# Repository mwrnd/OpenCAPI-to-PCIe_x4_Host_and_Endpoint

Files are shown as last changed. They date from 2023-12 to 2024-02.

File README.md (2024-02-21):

**Work-In-Progress**: Design being tested.

# OpenCAPI to PCIe x4 Host and Endpoint

Designed to test simultaneous PCIe Host and Endpoint operation with the Innova-2.

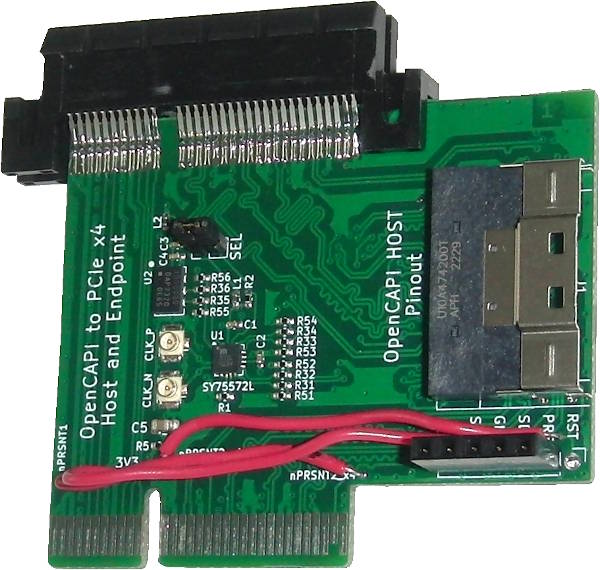
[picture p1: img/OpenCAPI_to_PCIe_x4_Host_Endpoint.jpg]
OpenCAPI to PCIe x4 Host and Endpoint Adapter


There are two [PCIE4](https://docs.xilinx.com/r/en-US/pg213-pcie4-ultrascale-plus/Introduction) blocks in the column of the Innova-2's OpenCAPI Quads.

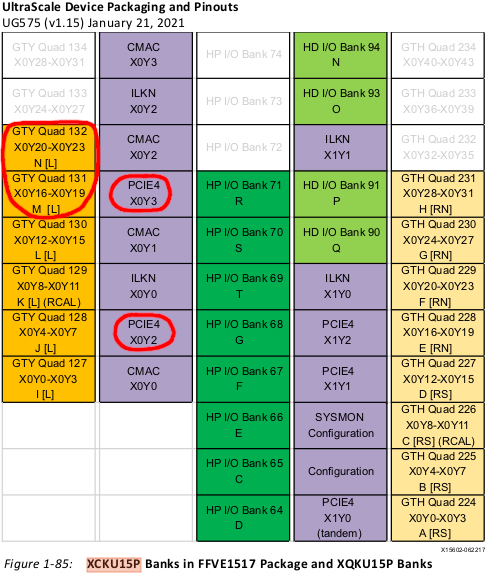
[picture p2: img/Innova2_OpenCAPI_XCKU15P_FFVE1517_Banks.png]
Innova-2 OpenCAPI Banks


The GTY Transceivers connected to the OpenCAPI Connector are in a column that does not contain the Configuration Block so it is impossible for the FPGA to be programmed within the [100ms PCIe power-up time limit](https://pcisig.com/specifications/ecr_ecn_process?speclib=100+ms). Motherboard boot must be delayed to allow the FPGA to configure itself before PCIe devices are enumerated. This can be accomplished by toggling the POWER button, then pressing and holding the RESET button for a second before releasing it. Or, [connect a capacitor across the reset pins of an ATX motherboard's Front Panel Header](https://github.com/mwrnd/ATX_Boot_Delay).

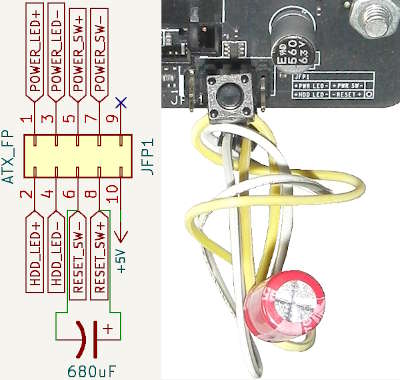
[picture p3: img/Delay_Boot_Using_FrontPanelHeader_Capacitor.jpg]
Delay Boot Using Front Panel Header Capacitor


[OpenCAPI](https://files.openpower.foundation/s/xSQPe6ypoakKQdq/download/25Gbps-spec-20171108.pdf)-compatible SlimSAS 8x uses a **Host** version of the OpenCAPI **Carrier** pinout from the [ADM-PCIE-9V5 User Manual (Pg15-19of38)](https://www.alpha-data.com/xml/user_manuals/adm-pcie-9v5%20user%20manual_v1_4.pdf).

## Testing

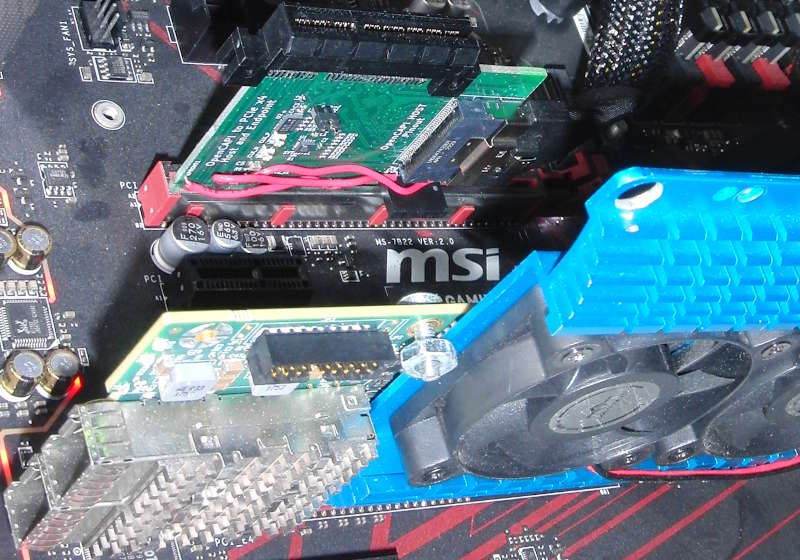
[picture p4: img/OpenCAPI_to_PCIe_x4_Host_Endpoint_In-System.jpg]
OpenCAPI to PCIe x4 Host and Endpoint in a System


```
TODO
```

### OpenCAPI I2C

The [innova2_xdma_opencapi](https://github.com/mwrnd/innova2_xdma_opencapi) project includes the ability to test I2C.

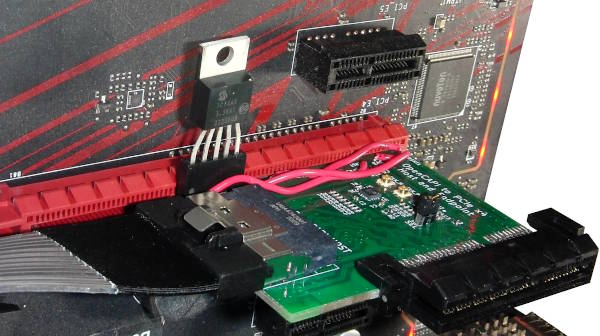
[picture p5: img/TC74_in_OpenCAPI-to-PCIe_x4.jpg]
Testing I2C using TC74


## PCB Layout

All differential pairs are length-matched to within 1mm intra-pair (N-to-P) and each group of differential pairs (e.g., TX0-to-TX3) is similarly matched to within 1mm.

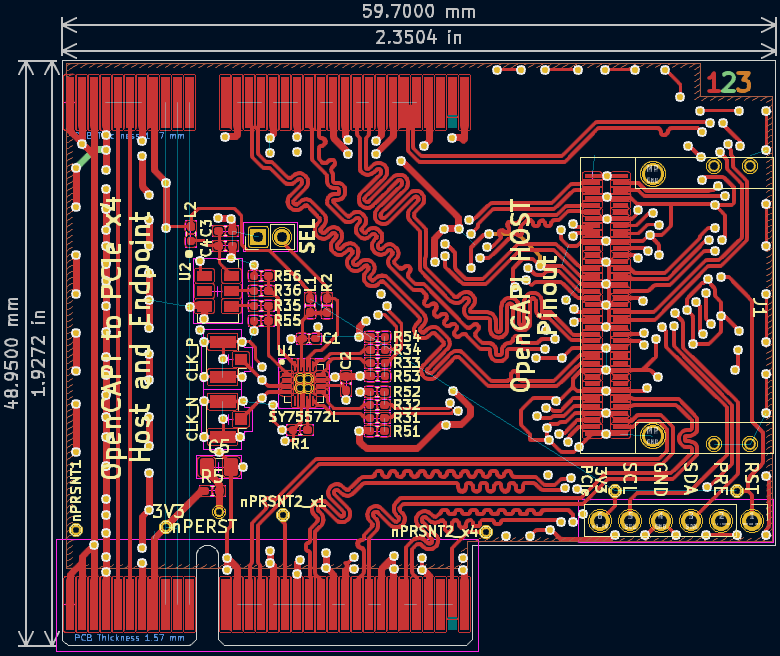
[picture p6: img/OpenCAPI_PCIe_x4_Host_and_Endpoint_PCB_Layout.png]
OpenCAPI to PCIe Host and Endpoint PCB Layout


## Schematic

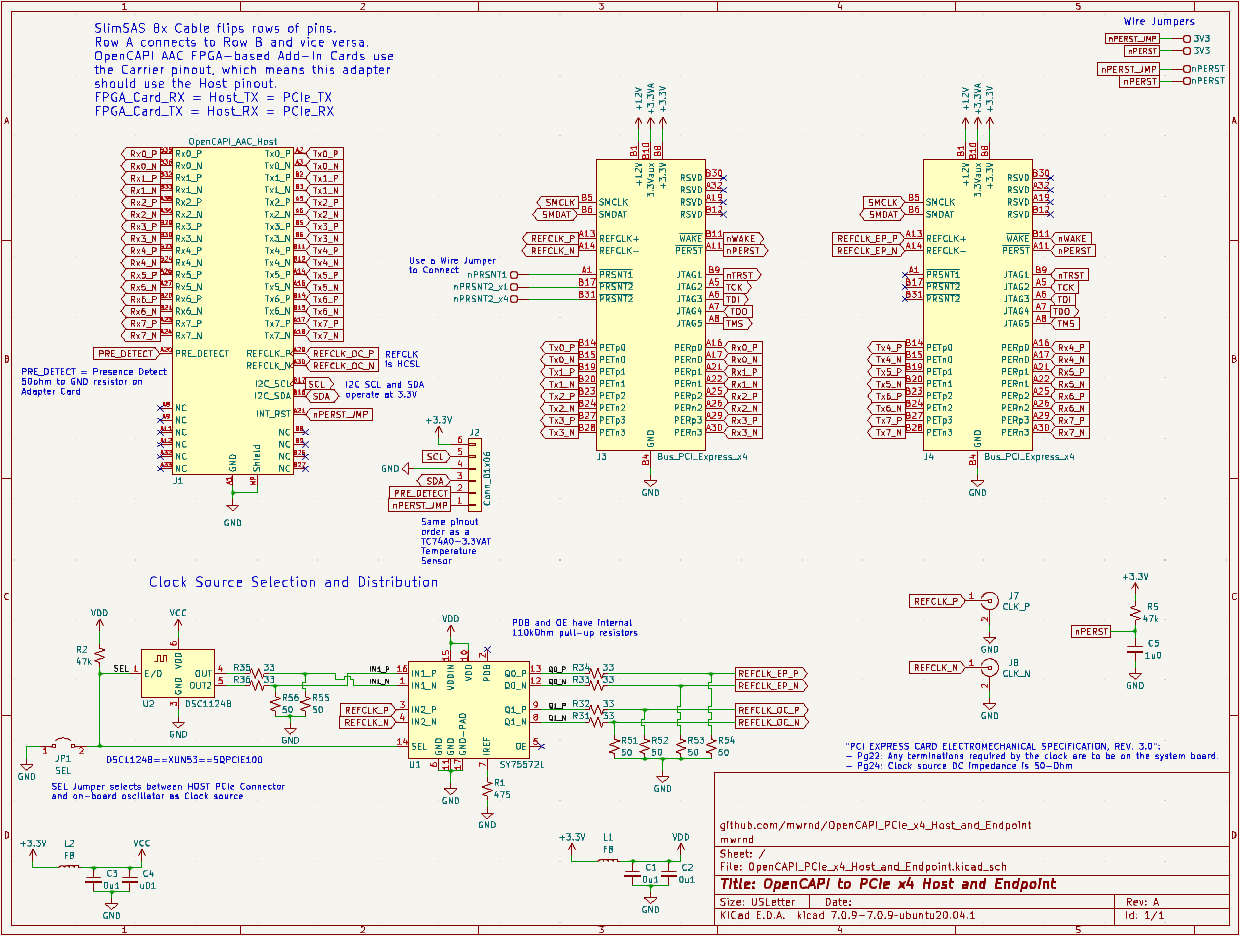
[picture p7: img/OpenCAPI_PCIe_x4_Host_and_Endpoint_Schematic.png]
OpenCAPI to PCIe Host and Endpoint Schematic


## Bill Of Materials

| Designator(s) | Part Number | Quantity | Value | Footprint | Availability |
| --- | --- | --- | --- | --- | --- |
| U1 | SY75572LMG | 1 | N/A | QFN-16-1EP_3x3mm_P0.5mm | [DigiKey](https://www.digikey.com/en/products/detail/microchip-technology/SY75572LMG-TR/5319585) |
| U2 | DSC1124BI2-100-0000 | 1 | N/A | OSC_SMD_IDT_JS6-6_5.0x3.2mm_P1.27mm | [DigiKey](https://www.digikey.com/en/products/detail/microchip-technology/DSC1124BI2-100-0000/5284202) |
| J1 | U10A474240T | 1 | N/A | SlimSAS_8x_RA_U10-A474 | [DigiKey](https://www.digikey.com/en/products/detail/amphenol-cs-commercial-products/U10A474240T/17066204) |
| J2 | PPPC061LFBN-RC | 1 | N/A | PinHeader_1x06_P2.54mm_Vertical | [DigiKey](https://www.digikey.com/en/products/detail/sullins-connector-solutions/PPPC061LFBN-RC/810178) |
| J4 | 2-2387405-2 | 1 | N/A | PCIe x4 Straddle Mount w/ Open End  | [DigiKey](https://www.digikey.com/en/products/detail/te-connectivity-amp-connectors/2-2387405-2/15221995) |
| JP1 | 2PH1-02-UA | 1 | N/A | PinHeader_1x02_P2.00mm_Vertical | [DigiKey](https://www.digikey.com/en/products/detail/adam-tech/2PH1-02-UA/9830305) |
| R31 to R36 | RT0402FRE0733RL | 6 | 33-Ohm | Resistor_SMD_R_0402_1005Metric | [DigiKey](https://www.digikey.com/en/products/detail/yageo/RT0402FRE0733RL/1071963) |
| R51 to R56 | RT0402FRE0749R9L | 6 | 49.9-Ohm | Resistor_SMD_R_0402_1005Metric | [DigiKey](https://www.digikey.com/en/products/detail/yageo/RT0402FRE0749R9L/1072042) |
| R1 | RT0402FRE07475RL | 1 | 475-Ohm | Resistor_SMD_R_0402_1005Metric | [DigiKey](https://www.digikey.com/en/products/detail/yageo/RT0402FRE07475RL/1072032) |
| R2, R5 | RT0402FRE0751KL | 2 | 51k-Ohm | Resistor_SMD_R_0402_1005Metric | [DigiKey](https://www.digikey.com/en/products/detail/yageo/RT0402FRE0751KL/1072058) |
| L1, L2 | BLM15PX601SN1D | 2 | 600@100MHz | Resistor_SMD_R_0402_1005Metric | [DigiKey](https://www.digikey.com/en/products/detail/murata-electronics/BLM15PX601SN1D/4421102) |
| C4 | KGM05AR71C103KH | 1 | 0.01uF | Capacitor_SMD_C_0402_1005Metric | [DigiKey](https://www.digikey.com/en/products/detail/kyocera-avx/KGM05AR71C103KH/563224) |
| C1, C2, C3 | KGM05AR51A104KH | 3 | 0.1uF | Capacitor_SMD_C_0402_1005Metric | [DigiKey](https://www.digikey.com/en/products/detail/kyocera-avx/KGM05AR51A104KH/563239) |
| C5 | CL21B105KAFNNNE | 1 | 1uF | Capacitor_SMD_C_0805_2012Metric | [DigiKey](https://www.digikey.com/en/products/detail/samsung-electro-mechanics/CL21B105KAFNNNE/3886724) |
| J7, J8 | 2337019-1 | 2 | U.FL(UMCC) | U.FL_Hirose | [DigiKey](https://www.digikey.com/en/products/detail/te-connectivity-amp-connectors/2337019-1/9974052) |
| Jumper | SPN02SYBN-RC | 1 | N/A | 2mm Shunt | [DigiKey](https://www.digikey.com/en/products/detail/sullins-connector-solutions/SPN02SYBN-RC/927356) |

**Optional**: [TC74Ax-3-3VAT](https://www.digikey.com/en/products/detail/microchip-technology/TC74A0-3-3VAT/442720) I2C Temperature Sensor for testing I2C.

## Assembly Notes

Use needle-nosed pliers to remove the PCIe x4 Connector's mounting post.

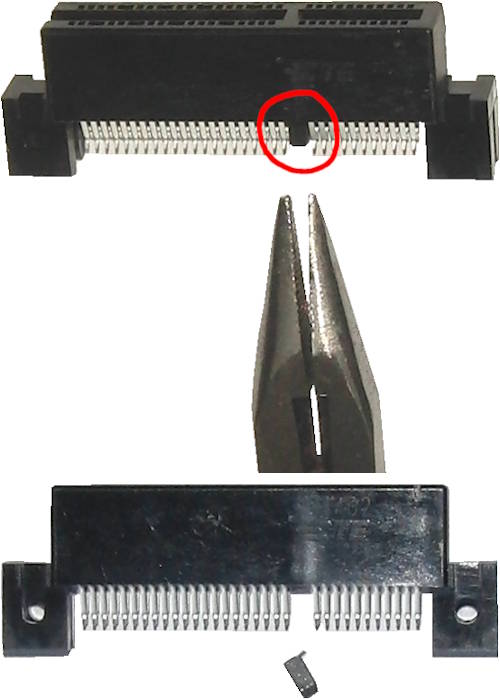
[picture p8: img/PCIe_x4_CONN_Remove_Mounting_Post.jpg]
Remove PCIe x4 CONNECTOR Mounting Post


Three wire jumpers are needed to connect `3V3==3V3_PCIe`, `nPERST==RST`, and `nPRSNT1==nPRSNT2_x4`.

## PCB Layer Stackup

4-Layer PCB stackup taken from [JLCPCB](https://jlcpcb.com/capabilities/pcb-capabilities).

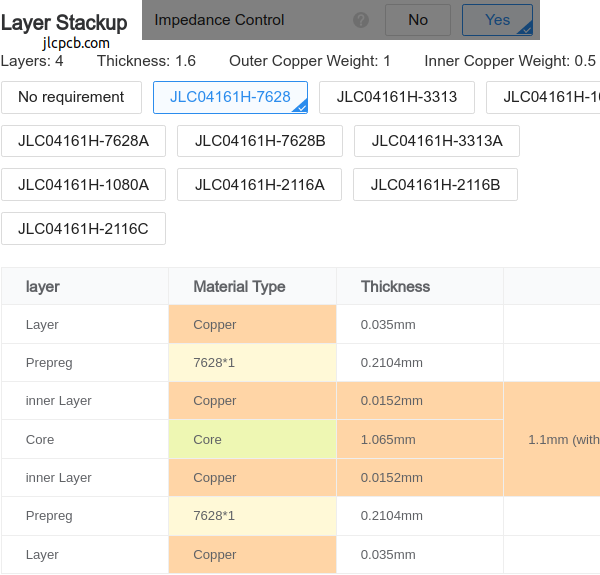
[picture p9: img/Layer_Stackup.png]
PCB Layer Stackup


Differential Impedance parameters were calculated using the [DigiKey Online Calculator](https://www.digikey.com/en/resources/conversion-calculators/conversion-calculator-pcb-trace-impedance).

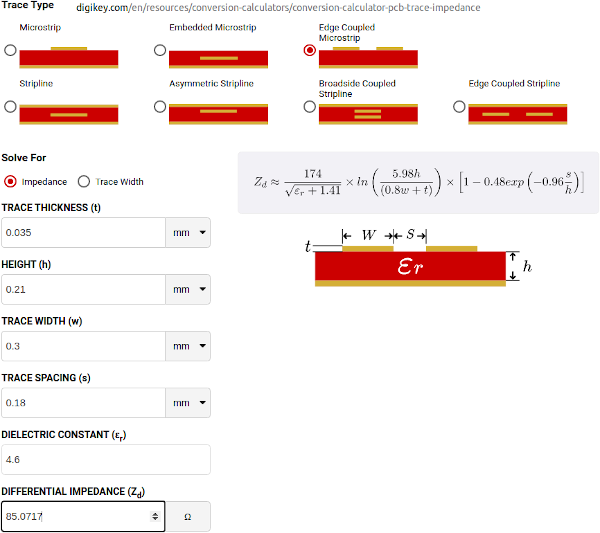
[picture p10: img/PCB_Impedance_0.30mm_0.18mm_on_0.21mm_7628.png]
PCB Differential Impedance Calculation


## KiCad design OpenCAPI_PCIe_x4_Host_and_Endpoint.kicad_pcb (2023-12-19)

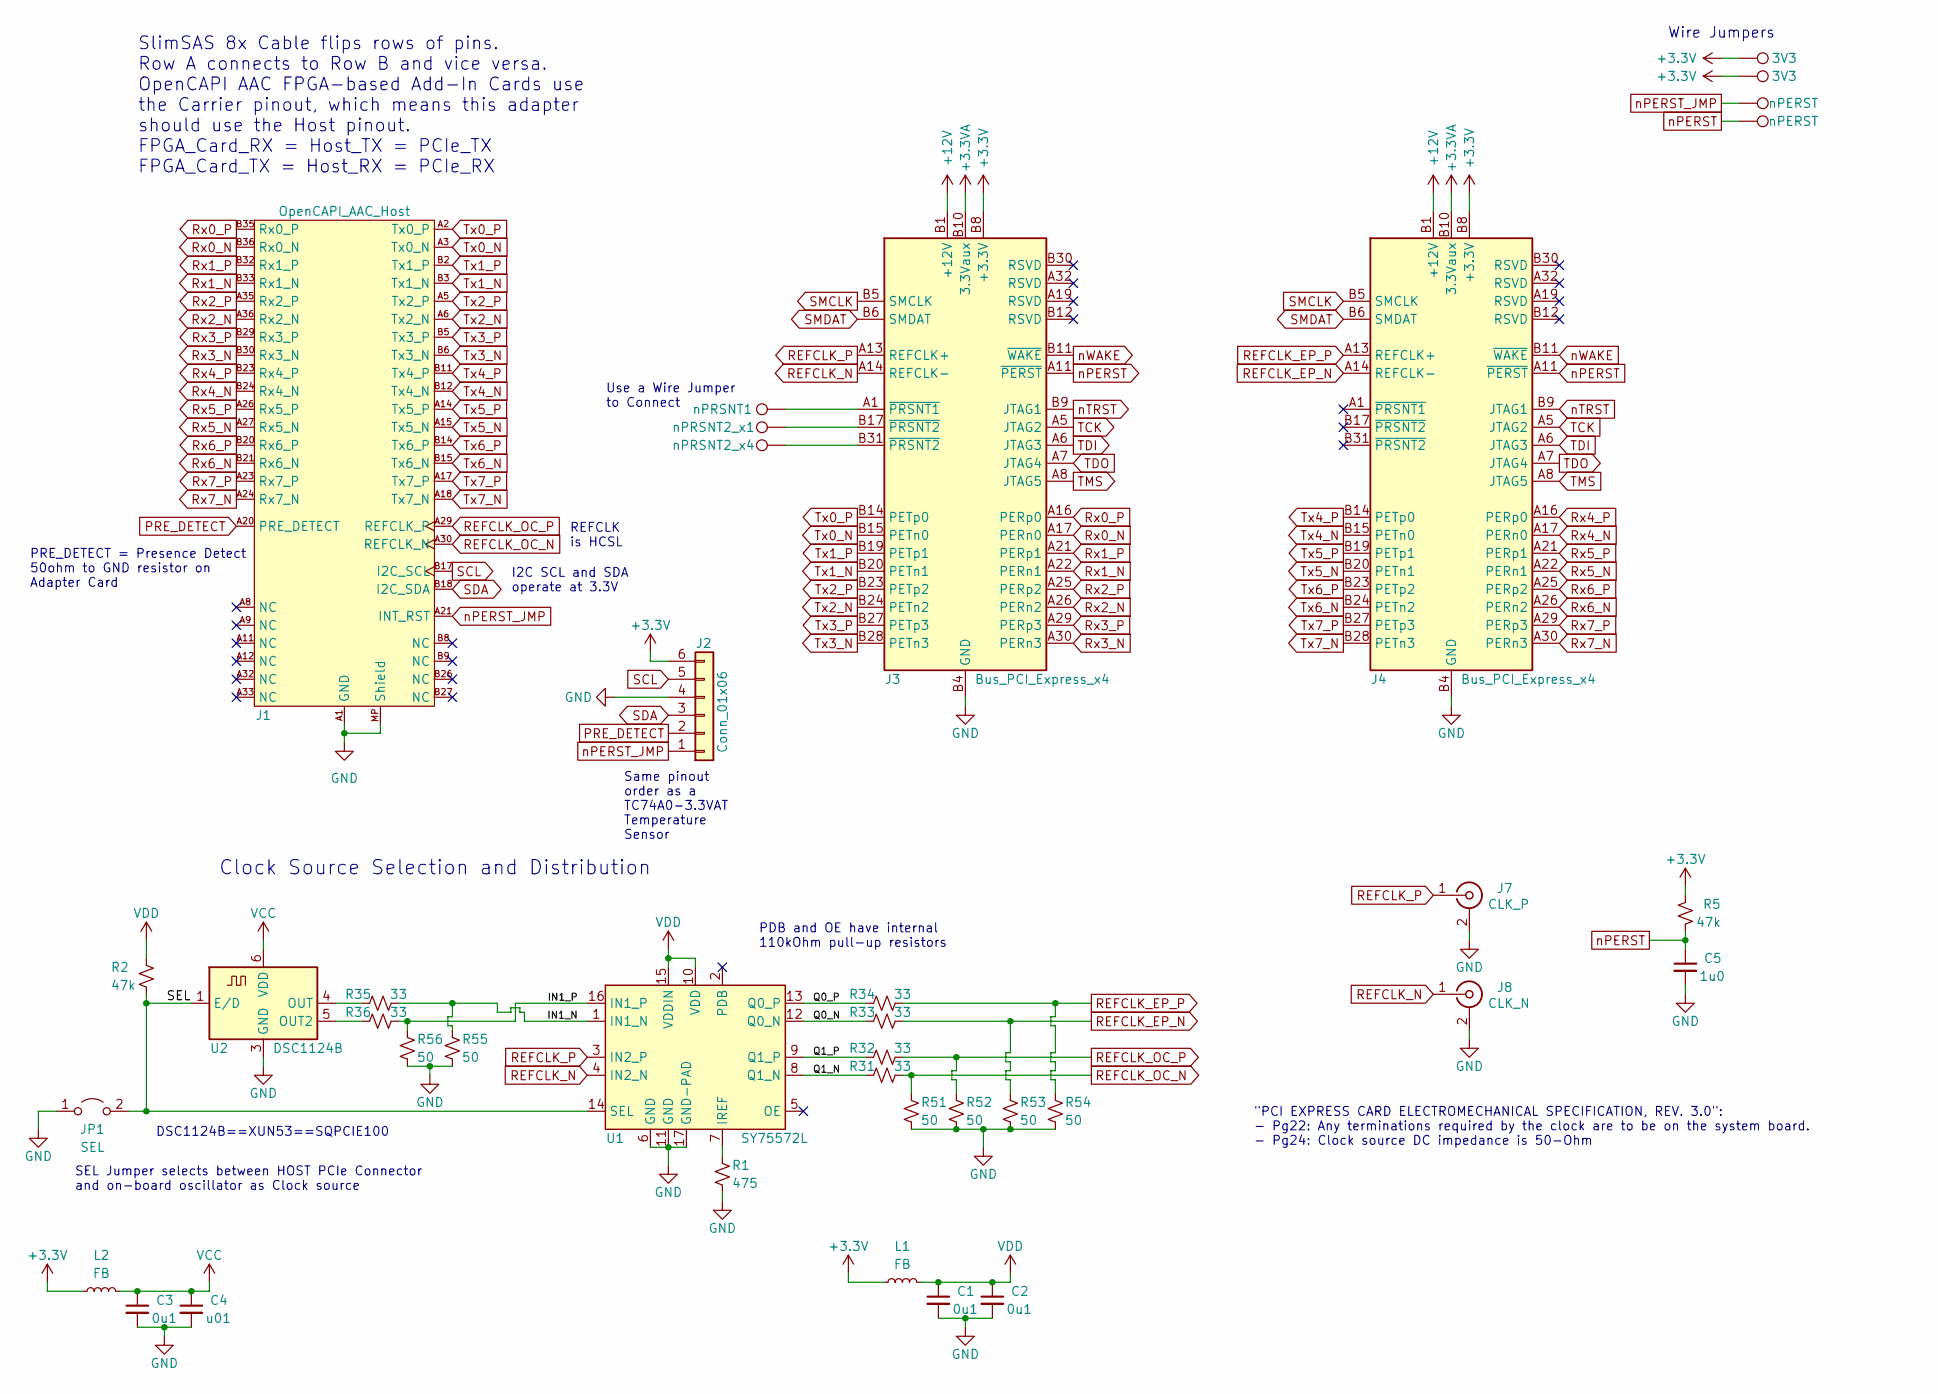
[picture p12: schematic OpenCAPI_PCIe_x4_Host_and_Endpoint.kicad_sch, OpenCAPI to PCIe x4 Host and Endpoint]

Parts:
C1, C2, C3: 0u1; C_0402_1005Metric_Pad0.74x0.62mm_HandSolder
C4: u01; C_0402_1005Metric_Pad0.74x0.62mm_HandSolder
C5: 1u0; C_0805_2012Metric_Pad1.18x1.45mm_HandSolder
J1: OpenCAPI_AAC_Host; SlimSAS_8x_RA_U10-A474
J2: Conn_01x06; PinHeader_1x06_P2.54mm_Vertical
J3, J4: Bus_PCI_Express_x4; BUS_PCIexpress_x4
J7: CLK_P; U.FL_Hirose_w_Label
J8: CLK_N; U.FL_Hirose_w_Label
JP1: SEL; PinHeader_1x02_P2.00mm_Vertical
L1, L2: FB; R_0402_1005Metric_Pad0.72x0.64mm_HandSolder
R1: 475; R_0402_1005Metric_Pad0.72x0.64mm_HandSolder
R2, R5: 47k; R_0402_1005Metric_Pad0.72x0.64mm_HandSolder
R31, R32, R33, R34, R35, R36: 33; R_0402_1005Metric_Pad0.72x0.64mm_HandSolder
R51, R52, R53, R54, R55, R56: 50; R_0402_1005Metric_Pad0.72x0.64mm_HandSolder
TP1: nPRSNT1; TestPoint_THTPad_D1.0mm_Drill0.5mm
TP2: nPRSNT2_x1; TestPoint_THTPad_D1.0mm_Drill0.5mm
TP3: nPRSNT2_x4; TestPoint_THTPad_D1.0mm_Drill0.5mm
TP4, TP5: 3V3; TestPoint_THTPad_D1.0mm_Drill0.5mm
TP6, TP7: nPERST; TestPoint_THTPad_D1.0mm_Drill0.5mm
U1: SY75572L; QFN-16-1EP_3x3mm_P0.5mm_EP1.45x1.45mm_ThermalVias
U2: DSC1124B; Oscillator_SMD_IDT_JS6-6_5.0x3.2mm_P1.27mm

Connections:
+3.3V: J2.6, J3.A9 (+3.3V), J3.A10 (+3.3V), J3.B8 (+3.3V), J4.A9 (+3.3V), J4.A10 (+3.3V), J4.B8 (+3.3V), L1.1, L2.1, R5.1, TP4.1, TP5.1
+3.3VA: J3.B10 (3.3Vaux), J4.B10 (3.3Vaux)
+12V: J3.A2 (+12V), J3.A3 (+12V), J3.B1 (+12V), J3.B2 (+12V), J3.B3 (+12V), J4.A2 (+12V), J4.A3 (+12V), J4.B1 (+12V), J4.B2 (+12V), J4.B3 (+12V)
/IN1_N: R35.1, R55.1, U1.1 (IN1_N)
/IN1_P: R36.1, R56.1, U1.16 (IN1_P)
/Q0_N: R33.2, U1.12 (Q0_N)
/Q0_P: R34.2, U1.13 (Q0_P)
/Q1_N: R31.2, U1.8 (Q1_N)
/Q1_P: R32.2, U1.9 (Q1_P)
/SEL: JP1.2 (B), R2.2, U1.14 (SEL), U2.1 (E/D)
GND: C1.2, C2.2, C3.2, C4.2, C5.2, J1.A1 (GND), J1.A4 (GND), J1.A7 (GND), J1.A10 (GND), J1.A13 (GND), J1.A16 (GND), J1.A19 (GND), J1.A22 (GND), J1.A25 (GND), J1.A28 (GND), J1.A31 (GND), J1.A34 (GND), J1.A37 (GND), J1.B1 (GND), J1.B4 (GND), J1.B7 (GND), J1.B10 (GND), J1.B13 (GND), J1.B16 (GND), J1.B19 (GND), J1.B22 (GND), J1.B25 (GND), J1.B28 (GND), J1.B31 (GND), J1.B34 (GND), J1.B37 (GND), J1.MP (Shield), J2.4, J3.A4 (GND), J3.A12 (GND), J3.A15 (GND), J3.A18 (GND), J3.A20 (GND), J3.A23 (GND), J3.A24 (GND), J3.A27 (GND), J3.A28 (GND), J3.A31 (GND), J3.B4 (GND), J3.B7 (GND), J3.B13 (GND), J3.B16 (GND), J3.B18 (GND), J3.B21 (GND), J3.B22 (GND), J3.B25 (GND), J3.B26 (GND), J3.B29 (GND), J3.B32 (GND), J4.A4 (GND), J4.A12 (GND), J4.A15 (GND), J4.A18 (GND), J4.A20 (GND), J4.A23 (GND), J4.A24 (GND), J4.A27 (GND), J4.A28 (GND), J4.A31 (GND), J4.B4 (GND), J4.B7 (GND), J4.B13 (GND), J4.B16 (GND), J4.B18 (GND), J4.B21 (GND), J4.B22 (GND), J4.B25 (GND), J4.B26 (GND), J4.B29 (GND), J4.B32 (GND), J7.2 (Ext), J8.2 (Ext), JP1.1 (A), R1.2, R51.2, R52.2, R53.2, R54.2, R55.2, R56.2, U1.6 (GND), U1.11 (GND), U1.17 (GND-PAD), U2.3 (GND)
unnamed: J3.A1 (~PRSNT1), TP1.1
unnamed: J3.B17 (~PRSNT2), TP2.1
unnamed: J3.B31 (~PRSNT2), TP3.1
unnamed: R1.1, U1.7 (IREF)
unnamed: R36.2, U2.5 (OUT2)
unnamed: R35.2, U2.4 (OUT)
PRE_DETECT: J1.A20 (PRE_DETECT), J2.2
REFCLK_EP_N: J4.A14 (REFCLK-), R33.1, R53.1
REFCLK_EP_P: J4.A13 (REFCLK+), R34.1, R54.1
REFCLK_N: J3.A14 (REFCLK-), J8.1 (In), U1.4 (IN2_N)
REFCLK_OC_N: J1.A30 (REFCLK_N), R31.1, R51.1
REFCLK_OC_P: J1.A29 (REFCLK_P), R32.1, R52.1
REFCLK_P: J3.A13 (REFCLK+), J7.1 (In), U1.3 (IN2_P)
Rx0_N: J1.B36 (Rx0_N), J3.A17 (PERn0)
Rx0_P: J1.B35 (Rx0_P), J3.A16 (PERp0)
Rx1_N: J1.B33 (Rx1_N), J3.A22 (PERn1)
Rx1_P: J1.B32 (Rx1_P), J3.A21 (PERp1)
Rx2_N: J1.A36 (Rx2_N), J3.A26 (PERn2)
Rx2_P: J1.A35 (Rx2_P), J3.A25 (PERp2)
Rx3_N: J1.B30 (Rx3_N), J3.A30 (PERn3)
Rx3_P: J1.B29 (Rx3_P), J3.A29 (PERp3)
Rx4_N: J1.B24 (Rx4_N), J4.A17 (PERn0)
Rx4_P: J1.B23 (Rx4_P), J4.A16 (PERp0)
Rx5_N: J1.A27 (Rx5_N), J4.A22 (PERn1)
Rx5_P: J1.A26 (Rx5_P), J4.A21 (PERp1)
Rx6_N: J1.B21 (Rx6_N), J4.A26 (PERn2)
Rx6_P: J1.B20 (Rx6_P), J4.A25 (PERp2)
Rx7_N: J1.A24 (Rx7_N), J4.A30 (PERn3)
Rx7_P: J1.A23 (Rx7_P), J4.A29 (PERp3)
SCL: J1.B17 (I2C_SCL), J2.5
SDA: J1.B18 (I2C_SDA), J2.3
SMCLK: J3.B5 (SMCLK), J4.B5 (SMCLK)
SMDAT: J3.B6 (SMDAT), J4.B6 (SMDAT)
TCK: J3.A5 (JTAG2), J4.A5 (JTAG2)
TDI: J3.A6 (JTAG3), J4.A6 (JTAG3)
TDO: J3.A7 (JTAG4), J4.A7 (JTAG4)
TMS: J3.A8 (JTAG5), J4.A8 (JTAG5)
Tx0_N: J1.A3 (Tx0_N), J3.B15 (PETn0)
Tx0_P: J1.A2 (Tx0_P), J3.B14 (PETp0)
Tx1_N: J1.B3 (Tx1_N), J3.B20 (PETn1)
Tx1_P: J1.B2 (Tx1_P), J3.B19 (PETp1)
Tx2_N: J1.A6 (Tx2_N), J3.B24 (PETn2)
Tx2_P: J1.A5 (Tx2_P), J3.B23 (PETp2)
Tx3_N: J1.B6 (Tx3_N), J3.B28 (PETn3)
Tx3_P: J1.B5 (Tx3_P), J3.B27 (PETp3)
Tx4_N: J1.B12 (Tx4_N), J4.B15 (PETn0)
Tx4_P: J1.B11 (Tx4_P), J4.B14 (PETp0)
Tx5_N: J1.A15 (Tx5_N), J4.B20 (PETn1)
Tx5_P: J1.A14 (Tx5_P), J4.B19 (PETp1)
Tx6_N: J1.B15 (Tx6_N), J4.B24 (PETn2)
Tx6_P: J1.B14 (Tx6_P), J4.B23 (PETp2)
Tx7_N: J1.A18 (Tx7_N), J4.B28 (PETn3)
Tx7_P: J1.A17 (Tx7_P), J4.B27 (PETp3)
VCC: C3.1, C4.1, L2.2, U2.6 (VDD)
VDD: C1.1, C2.1, L1.2, R2.1, U1.10 (VDD), U1.15 (VDDIN)
nPERST: C5.1, J3.A11 (~PERST), J4.A11 (~PERST), R5.2, TP7.1
nPERST_JMP: J1.A21 (INT_RST), J2.1, TP6.1
nTRST: J3.B9 (JTAG1), J4.B9 (JTAG1)
nWAKE: J3.B11 (~WAKE), J4.B11 (~WAKE)

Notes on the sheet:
PDB and OE have internal 110kOhm pull-up resistors
DSC1124B==XUN53==SQPCIE100
Clock Source Selection and Distribution
I2C SCL and SDA operate at 3.3V
Same pinout order as a TC74A0-3.3VAT Temperature Sensor
"PCI EXPRESS CARD ELECTROMECHANICAL SPECIFICATION, REV. 3.0": - Pg22: Any terminations required by the clock are to be on the system board. - Pg24: Clock source DC impedance is 50-Ohm
SEL Jumper selects between HOST PCIe Connector and on-board oscillator as Clock source
REFCLK is HCSL
SlimSAS 8x Cable flips rows of pins. Row A connects to Row B and vice versa. OpenCAPI AAC FPGA-based Add-In Cards use the Carrier pinout, which means this adapter should use the Host pinout. FPGA_Card_RX = Host_TX = PCIe_TX FPGA_Card_TX = Host_RX = PCIe_RX
Wire Jumpers
Use a Wire Jumper to Connect
PRE_DETECT = Presence Detect 50ohm to GND resistor on Adapter Card

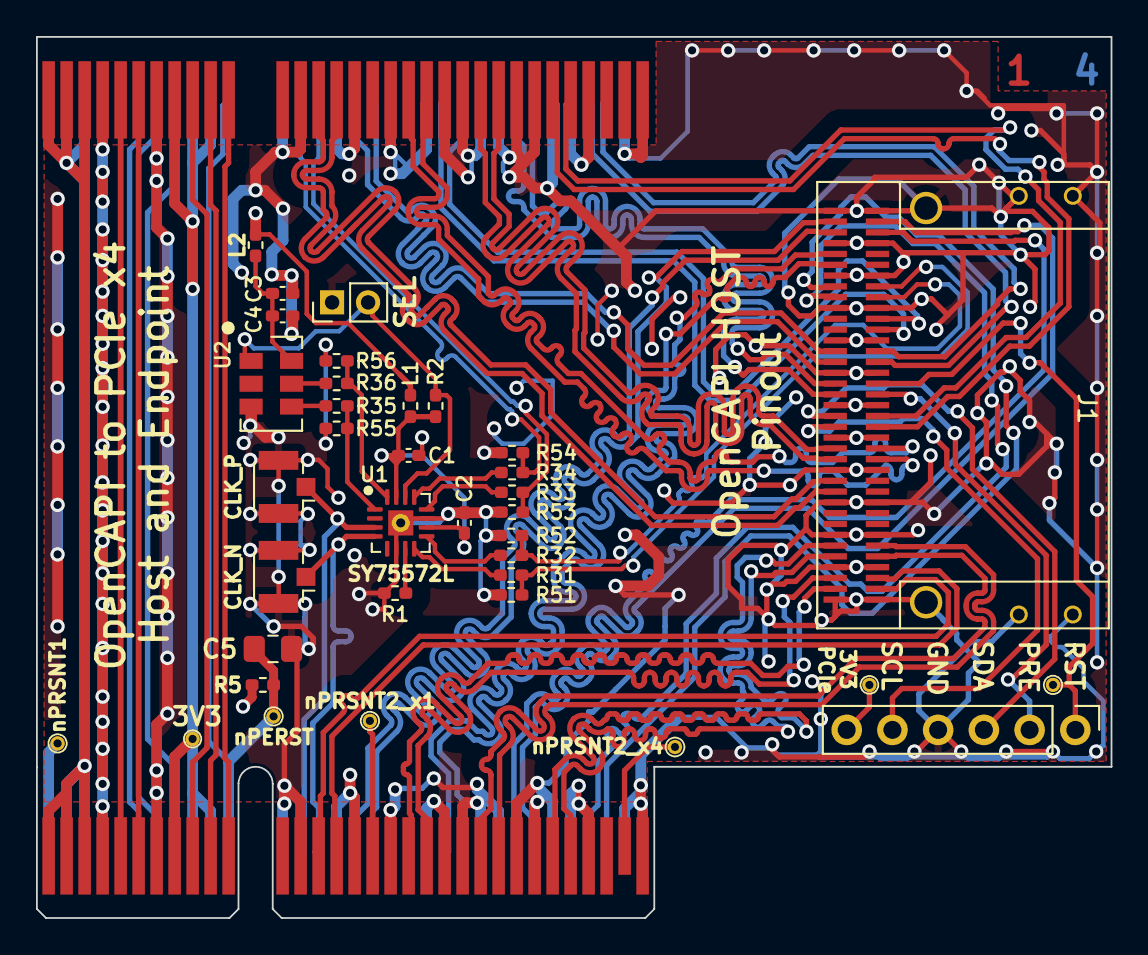
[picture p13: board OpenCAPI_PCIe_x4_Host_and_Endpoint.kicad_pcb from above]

Board: 4 copper layers, 59.7 x 49.0 mm, 38 parts (0 on the bottom side), 70 nets.

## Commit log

2023-12-19 First Revision Complete
    [OpenCAPI_PCIe_x4_Host_and_Endpoint.kicad_pcb, OpenCAPI_PCIe_x4_Host_and_Endpoint.kicad_sch]
2024-01-31 Bill Of Materials
